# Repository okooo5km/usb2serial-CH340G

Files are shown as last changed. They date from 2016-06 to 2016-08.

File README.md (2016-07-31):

## USB2TTL-CH340G

这是采用CH340G芯片的USB转UART模块的KiCAD工程设计文件，同时可以作为Arduino下载器。

#### 目标功能

1. 通用的usb转uart功能
2. 为Arduino下载程序
3. 自由选择3.3V或5V供电和信号电平模式。
4. 电源LED指示、TX和RX的LED指示

#### 原理图

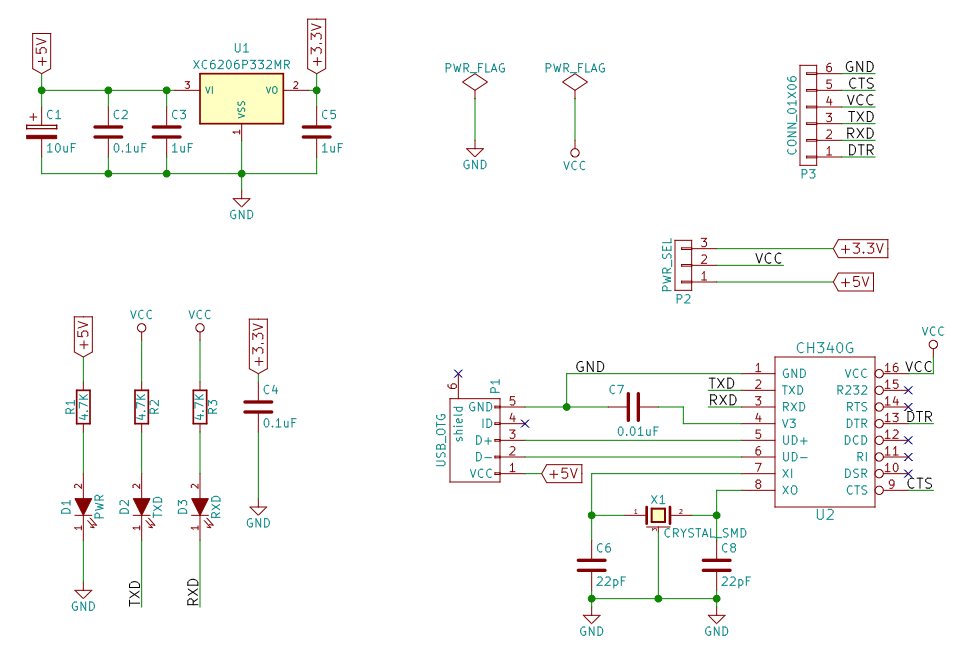
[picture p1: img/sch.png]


#### PCB

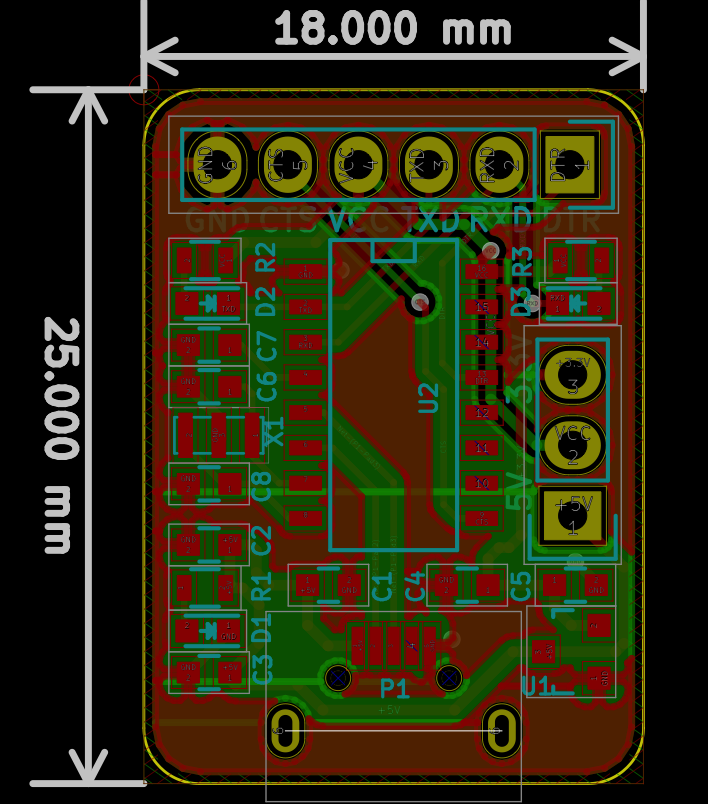
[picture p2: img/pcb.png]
pcb


#### PCB的3D预览

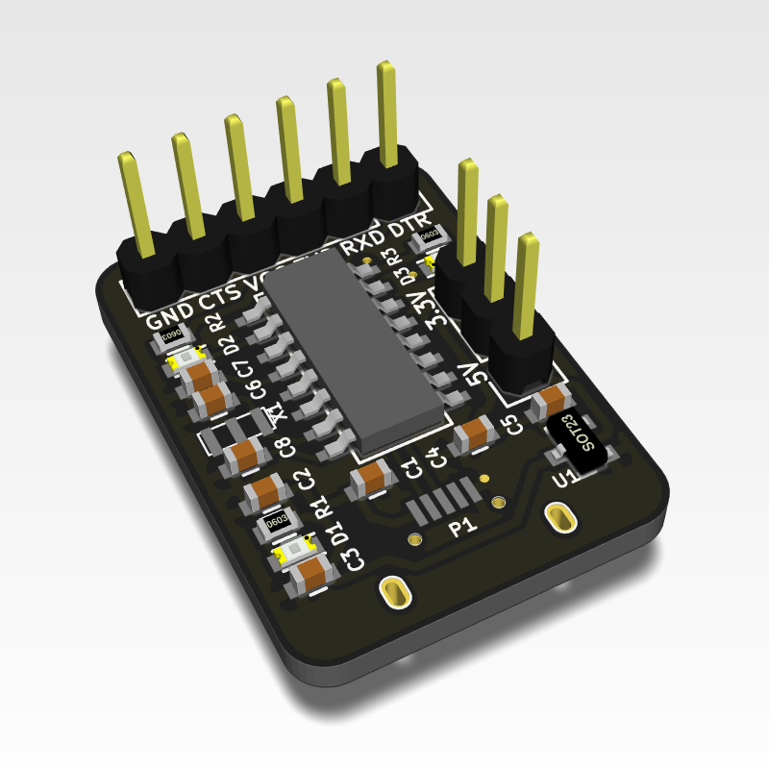
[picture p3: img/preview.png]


#### 附：

[CH340](http://www.wch.cn/product/CH340.html) 是一个 USB 总线的转接芯片,实现 USB 转串口、USB 转 IrDA 红外或者 USB 转打印口，其中设计中采用的CH340G是一款只有USB转串口功能的芯片。

##### I. 芯片驱动

1. [windows驱动](http://www.wch.cn/download/CH341SER_ZIP.html)
2. [Mac OSX驱动](http://www.wch.cn/download/CH341SER_MAC_ZIP.html)
3. [Linux驱动](http://www.wch.cn/download/CH341SER_LINUX_ZIP.html)

##### II. 注意

电路完成焊接后，因为稳压二极管的性能误差，可能会造成输出的3.3V不准，电压低于3.2V时可能会造成Mac电脑在使用3.3V的工作模式时UART通信有问题。可以通过更换稳压二极管或者更小阻值的电阻R3来解决。

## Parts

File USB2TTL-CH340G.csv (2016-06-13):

Reference | Value | Footprint | Datasheet
P4 | CONN_01X06 | Pin_Headers:Pin_Header_Straight_1x06
C1 | 10uF | Capacitors_SMD:C_0603
C4 | 10uF | Capacitors_SMD:C_0603
C2 | 0.1uF | Capacitors_SMD:C_0603
R3 | 100 | Resistors_SMD:R_0603
R1 | 4.7K | Resistors_SMD:R_0603
R2 | 4.7K | Resistors_SMD:R_0603
R4 | 4.7K | Resistors_SMD:R_0603
C3 | 0.1uF | Capacitors_SMD:C_0603
D1 | PWR | LEDs:LED_0603
D2 | TXD | LEDs:LED_0603
D3 | RXD | LEDs:LED_0603
C5 | 22pF | Capacitors_SMD:C_0603
C6 | 22pF | Capacitors_SMD:C_0603
D4 | 3V3 | Diodes_SMD:SOD-123
U1 | CH340G | SMD_Packages:SO-16-N
P1 | PWR | Pin_Headers:Pin_Header_Straight_1x03
P3 | PWR_SEL | Pin_Headers:Pin_Header_Straight_1x03
X1 | CRYSTAL_SMD | myFootprints:Resonator_3.2x1.5mm
P2 | USB_OTG | myFootprints:USB_Micro-B-MK5
C7 | 0.01uF | Capacitors_SMD:C_0603

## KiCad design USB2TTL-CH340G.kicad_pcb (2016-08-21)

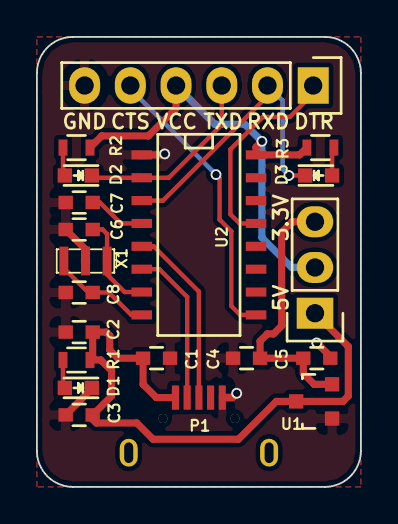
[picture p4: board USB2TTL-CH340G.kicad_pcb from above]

Board: 2 copper layers, 18.0 x 25.0 mm, 20 parts (0 on the bottom side), 16 nets.

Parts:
C1: 10uF; C_0603
C2, C4: 0.1uF; C_0603
C3, C5: 1uF; C_0603
C6, C8: 22pF; C_0603
C7: 0.01uF; C_0603
D1: PWR; LED_0603
D2: TXD; LED_0603
D3: RXD; LED_0603
P1: USB_OTG; USB_Micro-B-MK5
P2: PWR_SEL; Pin_Header_Straight_1x03
P3: CONN_01X06; Pin_Header_Straight_1x06
R1, R2, R3: 4.7K; R_0603
U1: XC6206P332MR; SOT-23
U2: CH340G; SO-16-N
X1: CRYSTAL_SMD; Resonator_3.2x1.5mm

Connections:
+3.3V: C4.1, C5.1, P2.3, U1.2
+5V: C1.1, C2.1, C3.1, P1.1, P2.1, R1.2, U1.3
/CTS: P3.5, U2.9
/DTR: P3.1, U2.13
/RXD: D3.1, P3.2, U2.3
/TXD: D2.1, P3.3, U2.2
GND: C1.2, C2.2, C3.2, C4.2, C5.2, C6.2, C7.2, C8.2, D1.1, P1.5, P3.6, U1.1, U2.1, X1.3
unnamed: C6.1, U2.7, X1.1
unnamed: C7.1, U2.4
unnamed: C8.1, U2.8, X1.2
unnamed: D1.2, R1.1
unnamed: D2.2, R2.2
unnamed: D3.2, R3.2
unnamed: P1.2, U2.6
unnamed: P1.3, U2.5
VCC: P2.2, P3.4, R2.1, R3.1, U2.16

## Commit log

2016-06-12 添加版本v0.01的设计文件及相关的描述文件和图片
    [USB2TTL-CH340G.csv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]
2016-06-12 更新为版本v0.2，修改内容如下：1.修复电源电路连接问题（v3和VCC）。2.重新布局使元件更紧凑，板型加入圆角。3.更改USB接口的封装。4.导出最新gerber及drill钻孔文件。
    [USB2TTL-CH340G-B.Cu.gbr, USB2TTL-CH340G-B.Mask.gbr, USB2TTL-CH340G-B.SilkS.gbr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]
2016-06-13 更新bom，README添加芯片信息，修改忽略文件
    [USB2TTL-CH340G.csv]
2016-06-13 1.README中加入驱动链接及注意事项；2.更改R3电阻阻值为200欧姆；3.修改gitignore文件忽略bak文件。
    [USB2TTL-CH340G.kicad_pcb, USB2TTL-CH340G.sch]
2016-06-20 修改micro usb封装，添加定位孔，更新pcb封装
    [USB2TTL-CH340G.kicad_pcb]
2016-07-31 删掉对外供电的插针，重新布局设计PCB，大小为25mmX18mm，并导出单板的gerber文件和钻孔文件
    [USB2TTL-CH340G-B.Cu.gbr, USB2TTL-CH340G-B.Mask.gbr, USB2TTL-CH340G-B.SilkS.gbr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]
2016-07-31 更新README，并更新截图
2016-08-21 1.新建myRegul库并添加元件LDO芯片XP6206；2.用最大可提供500mA电流的XP6206替换掉原来的二极管稳压电路，提高稳定性；3.调整PCB元件布局。
    [USB2TTL-CH340G-B.Cu.gbr, USB2TTL-CH340G-B.Mask.gbr, USB2TTL-CH340G-B.SilkS.gbr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]
2016-08-21 拼板导出相应gerber和drill文件
    [USB2TTL-CH340G-B.Cu.gbr, USB2TTL-CH340G-B.Mask.gbr, USB2TTL-CH340G-B.SilkS.gbr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]
